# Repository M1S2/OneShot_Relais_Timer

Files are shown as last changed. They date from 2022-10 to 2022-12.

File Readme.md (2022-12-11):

# OneShot Relais Timer

This is a relais timer module that switches a AC mains load ON for a defined period of time.

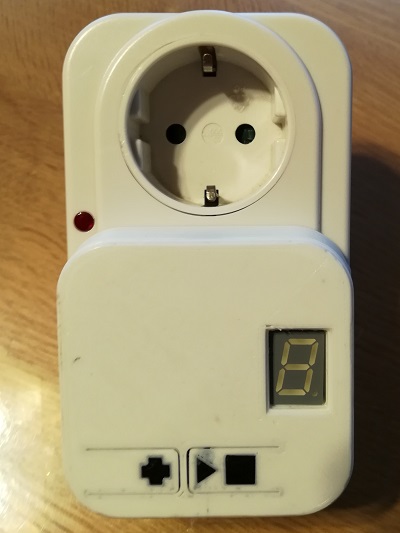
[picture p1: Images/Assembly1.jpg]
Assembly1


## PCB
The schematics and PCBs were created using EAGLE. They were designed to be manufactured using toner transfer method so all traces are as big as possible.

There are two PCBs:
- The Main_PCB contains the microcontroller, the relay and the transformer and regulators used to generate all needed voltages.

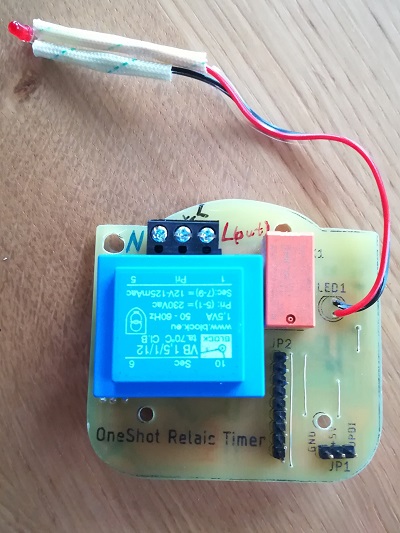
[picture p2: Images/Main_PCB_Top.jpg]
	
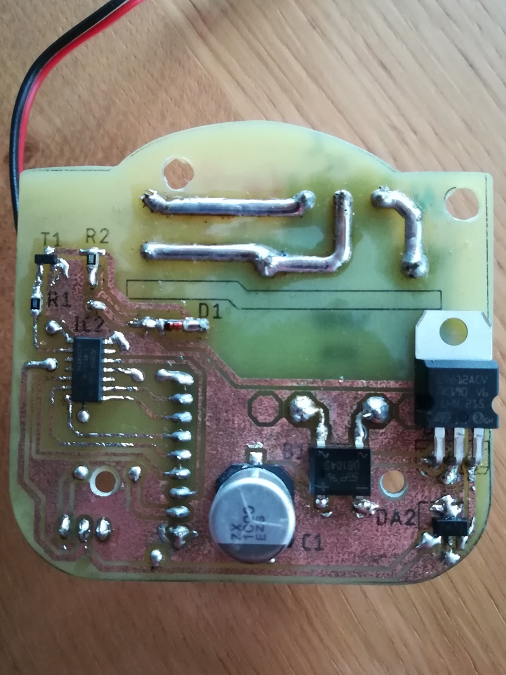
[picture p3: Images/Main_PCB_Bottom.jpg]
	
- The UI_PCB contains the buttons, the 7-segment display and the needed BCD-7-segment driver IC.

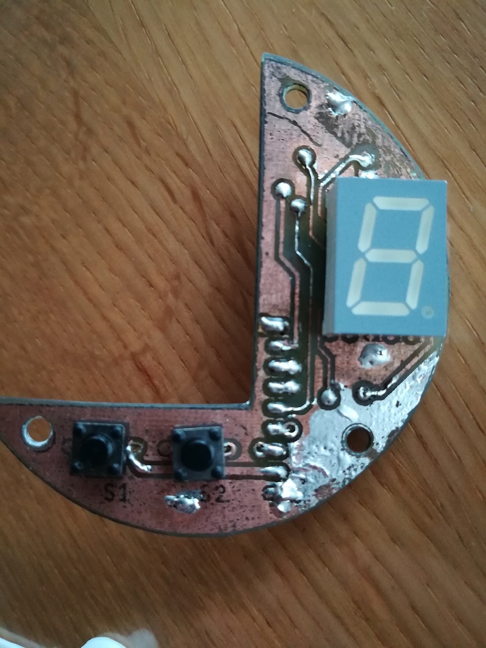
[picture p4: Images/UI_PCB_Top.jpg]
	
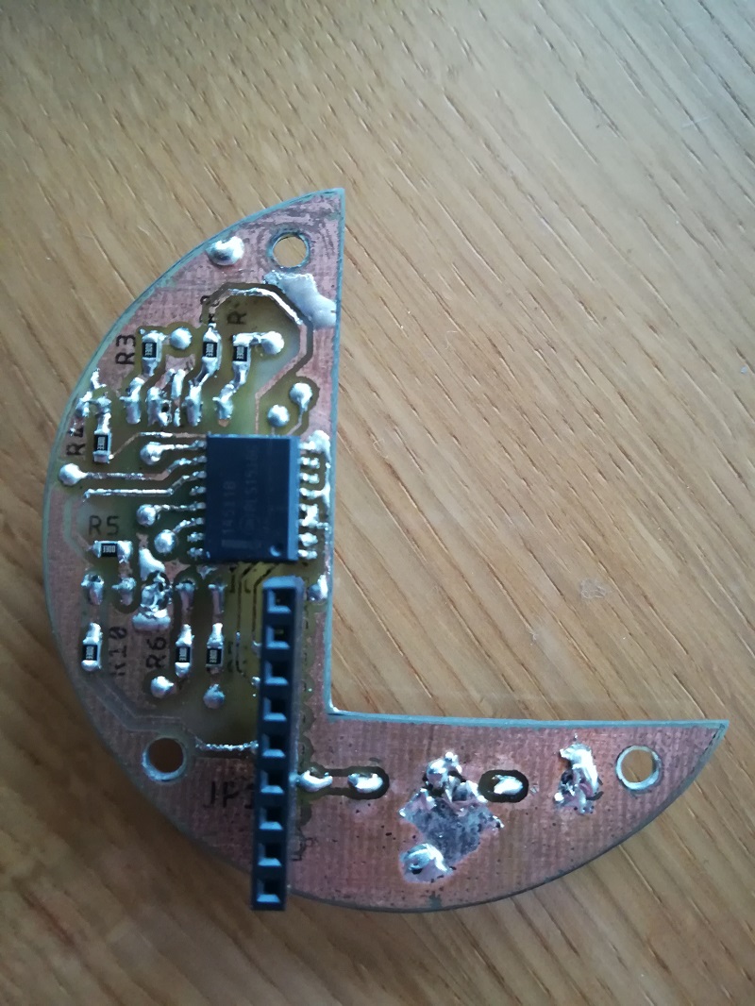
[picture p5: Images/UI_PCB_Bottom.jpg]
	

## Housing
The housing of a mechanical timer was used to containg the PCBs.
The following parts are needed additionally:
- 1x Grundplatte.stl
- 1x Abdeckung_Symbole.stl (should be printed with 2 colors)
- 3x Spacer.stl
- 3x Screw M3x30
- 1x Screw M3x12
- 4x Sheet Metal Screw 15mm long

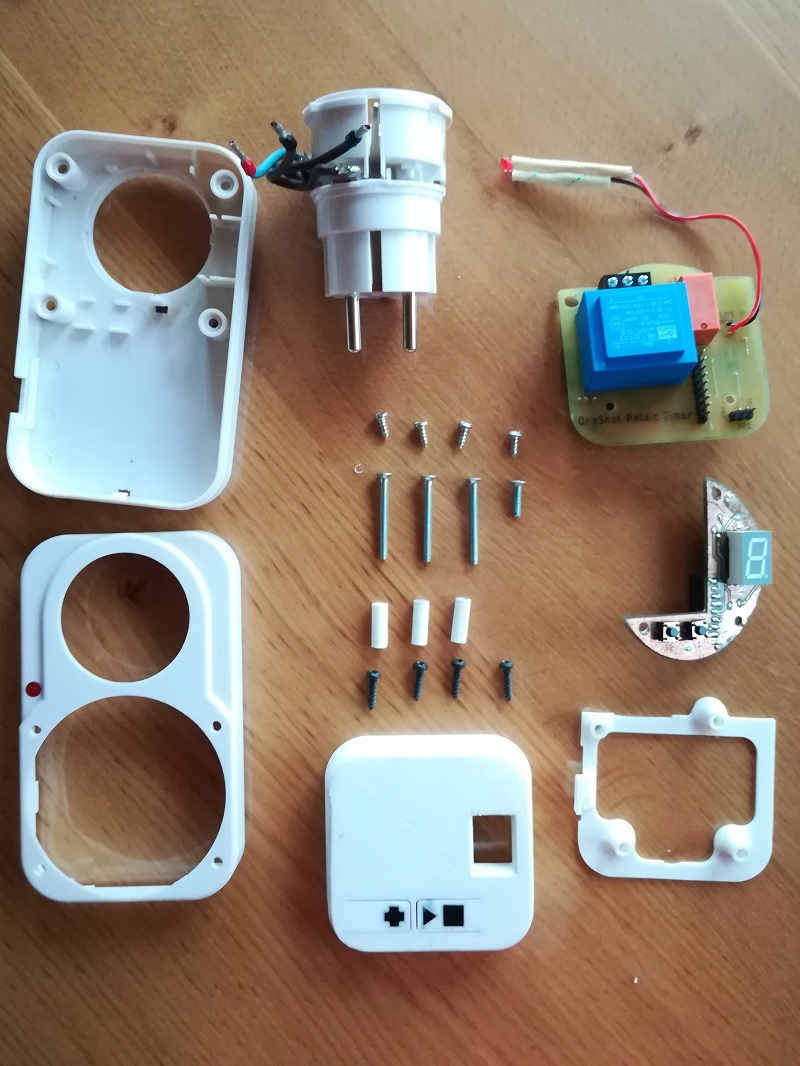
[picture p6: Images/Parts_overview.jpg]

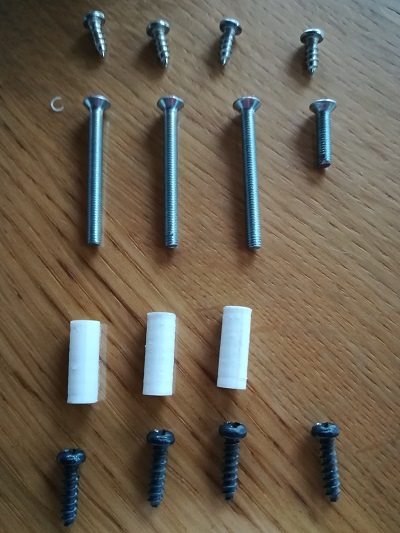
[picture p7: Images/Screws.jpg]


## Software
The software was written for the ATTiny204 microcontroller.

A statemachine is running in the main loop with the following two states:
- SET: The hours can be modified using the set button. The allowed range is 0 to 9. If the start/stop button is pressed, the relay is toggled and the state is changed to COUNTDOWN.
- COUNTDOWN: If the remaining seconds are equal 0 (counted by the PIT interrupt) or the start/stop button is pressed, the relay is toggled and the state is changed to SET.

It uses the following peripherals:
- TCA0: Timer used to query the buttons. It calls the button debounce routine of Peter Dannegger (http://www.mikrocontroller.net/articles/Entprellung).
- PIT: Periodic Interrupt Timer used to count the remaining seconds in COUNTDOWN mode. It also toggles the 7-segment dot in COUNTDOWN mode.

### 0-hours
If the hours are set to 0, the start/stop button can be used to directly toggle the relay. By toggling the relay, an inverted mode is activated, because the relay is toggled when the (normal) countdown is started.
E.g.:
- The set button is used to set the hours to 0
- The start/stop button is used to toggle the relay on.
- The set button is used to set the hours to e.g. 1
- The start/stop button is used to start the countdown > the relay is switched off and on after 1 hour (inverted mode)

### Last set hour
The last set hours are saved when the Countdown is started and are reload on startup.

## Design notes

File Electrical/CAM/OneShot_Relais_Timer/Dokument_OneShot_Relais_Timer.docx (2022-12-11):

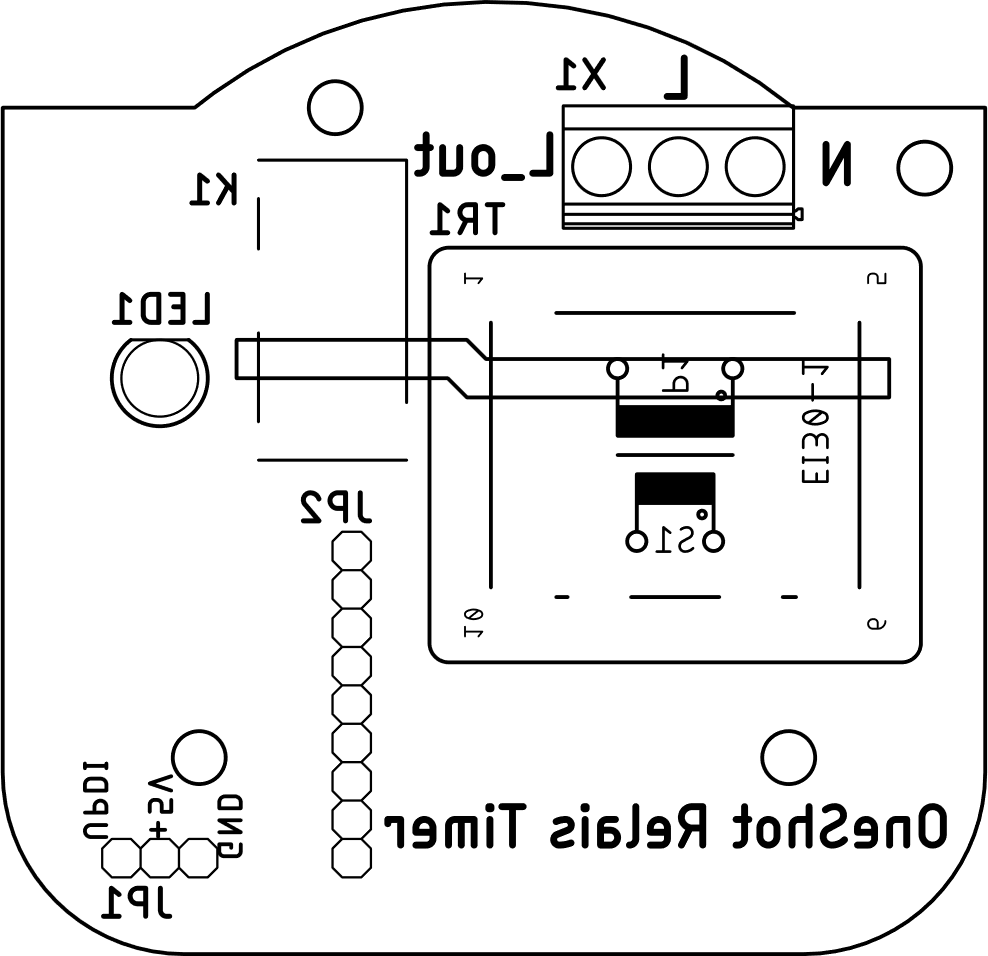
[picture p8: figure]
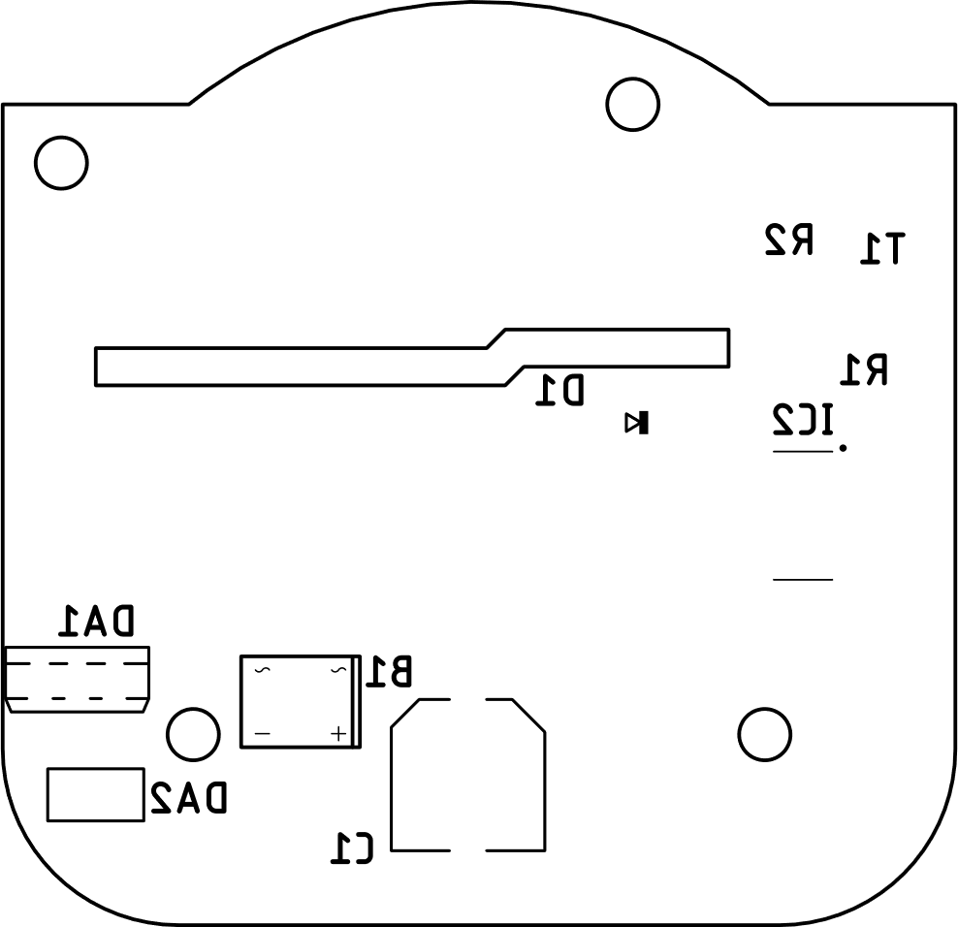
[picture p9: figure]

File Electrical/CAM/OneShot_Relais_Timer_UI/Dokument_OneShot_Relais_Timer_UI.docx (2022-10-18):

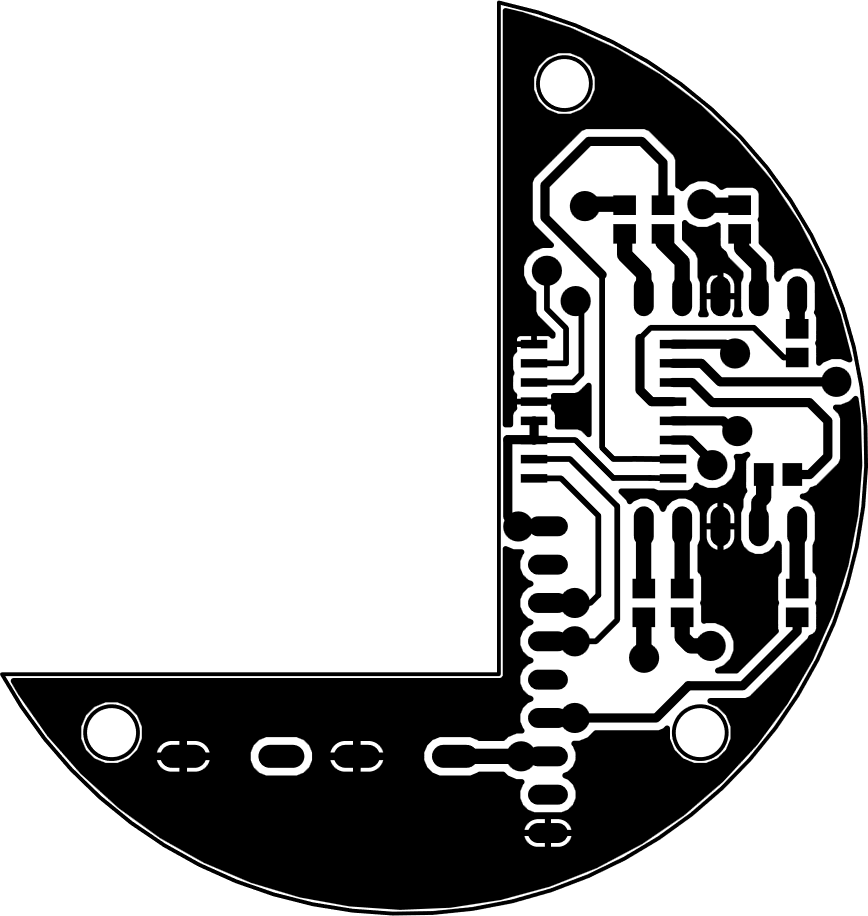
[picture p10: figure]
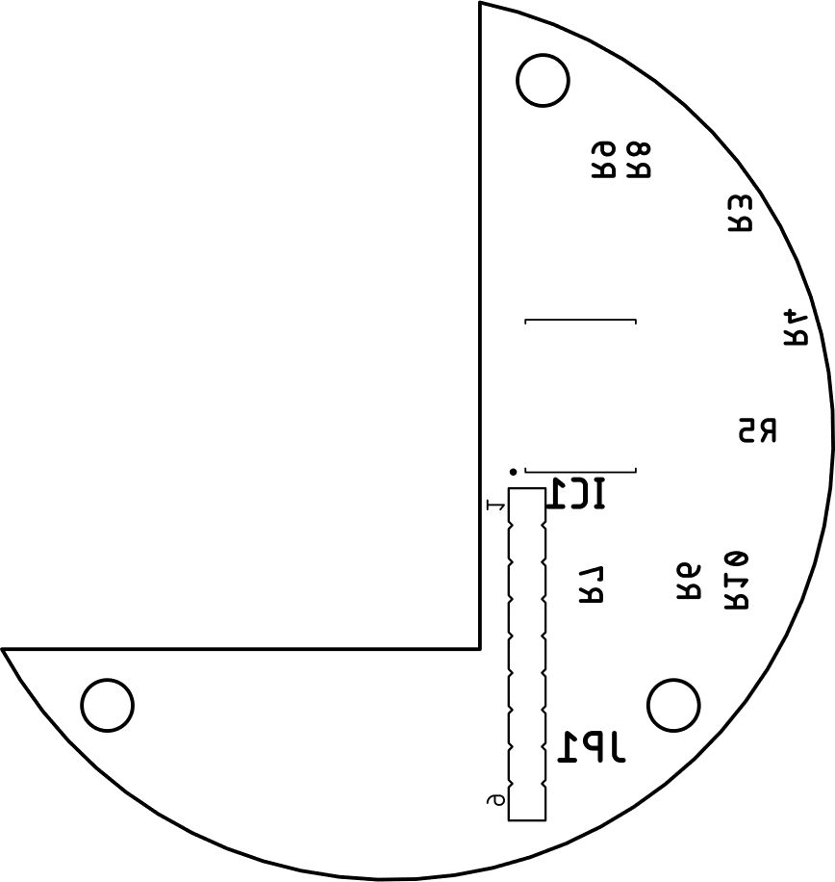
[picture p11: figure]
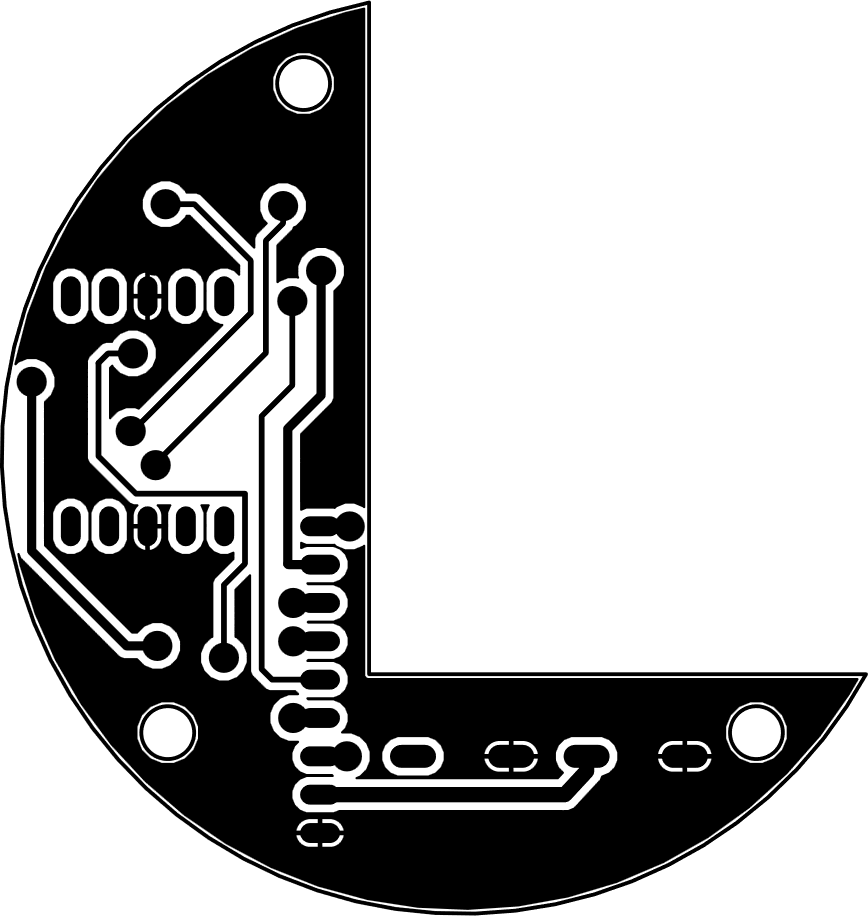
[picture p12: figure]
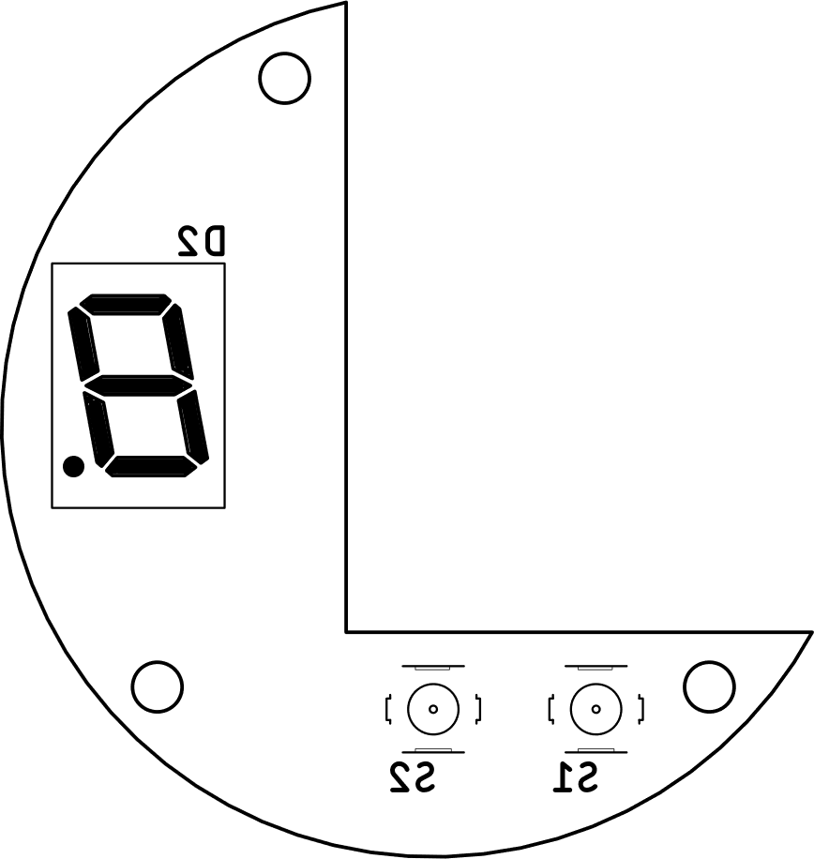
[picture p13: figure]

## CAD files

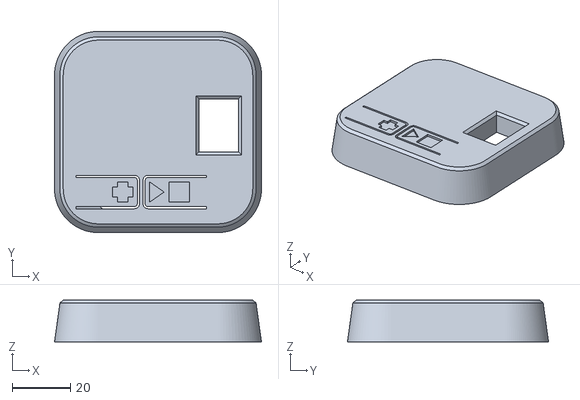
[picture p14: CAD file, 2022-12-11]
Mechanical/Abdeckung.stl
71.0 x 69.0 x 14.4

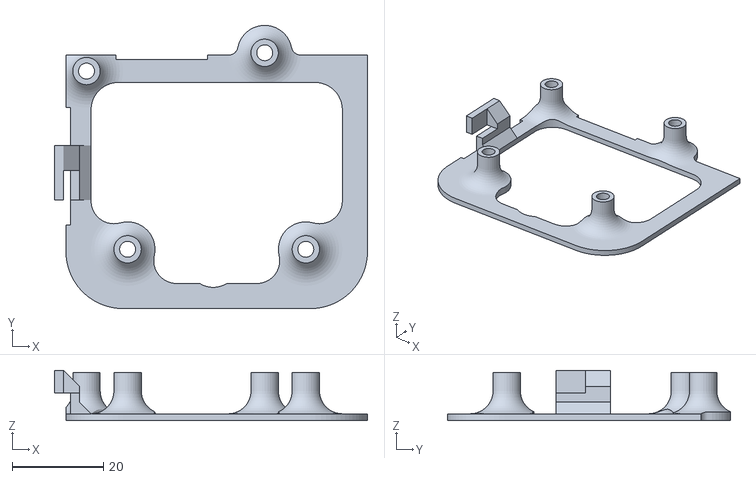
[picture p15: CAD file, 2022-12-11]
Mechanical/Grundplatte.stl
68.5 x 62.0 x 11.0

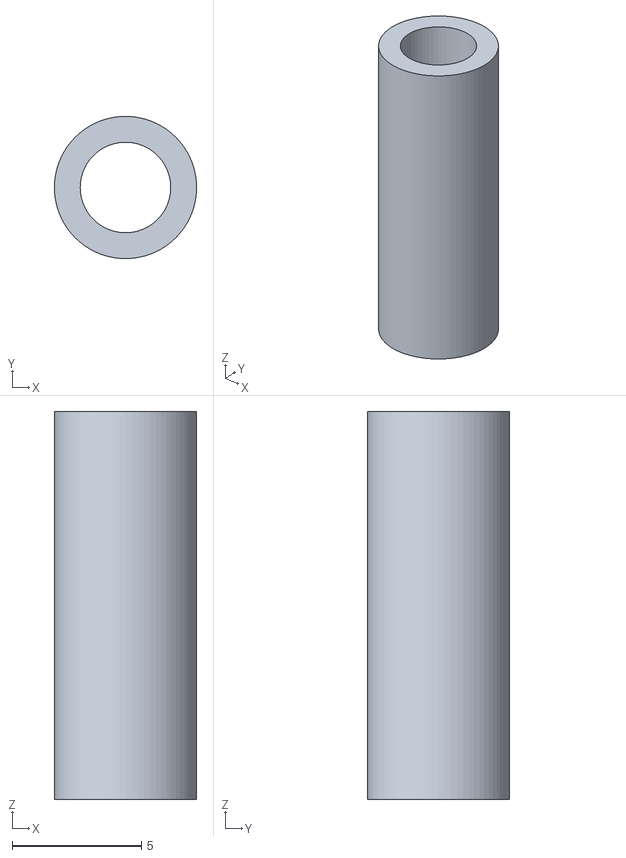
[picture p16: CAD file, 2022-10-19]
Mechanical/Spacer.stl
5.50 x 5.50 x 15.0

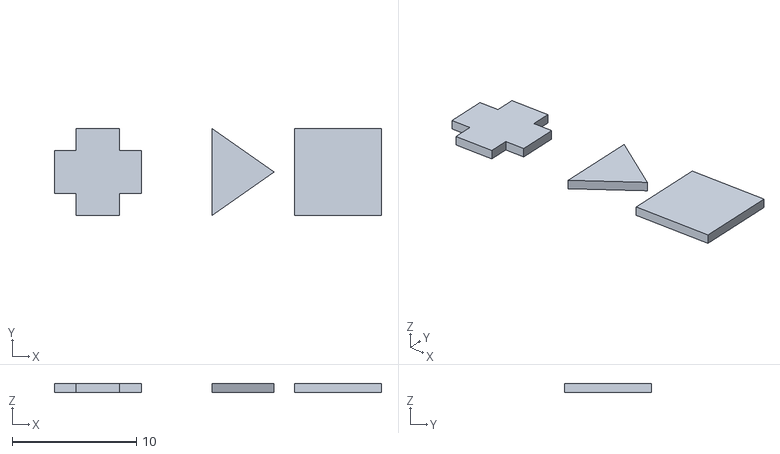
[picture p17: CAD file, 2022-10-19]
Mechanical/Abdeckung_Symbole.stl
26.3 x 7.00 x 0.75

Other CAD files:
Mechanical/Abdeckung.f3d
Mechanical/Abdeckung_Symbole.f3d
Mechanical/Gehaeuse_oben.f3d
Mechanical/Gehaeuse_unten.f3d
Mechanical/Grundplatte.f3d
Mechanical/Spacer.f3d

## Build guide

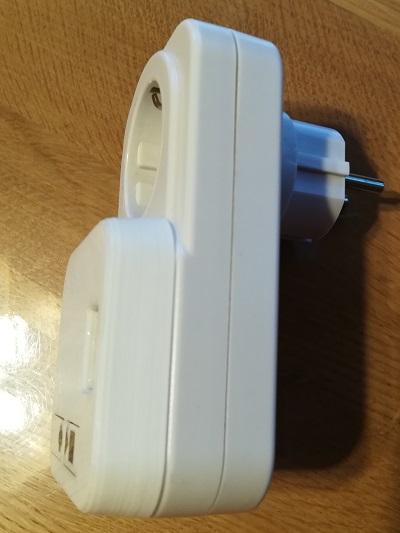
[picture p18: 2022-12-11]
Images/Assembly2.jpg

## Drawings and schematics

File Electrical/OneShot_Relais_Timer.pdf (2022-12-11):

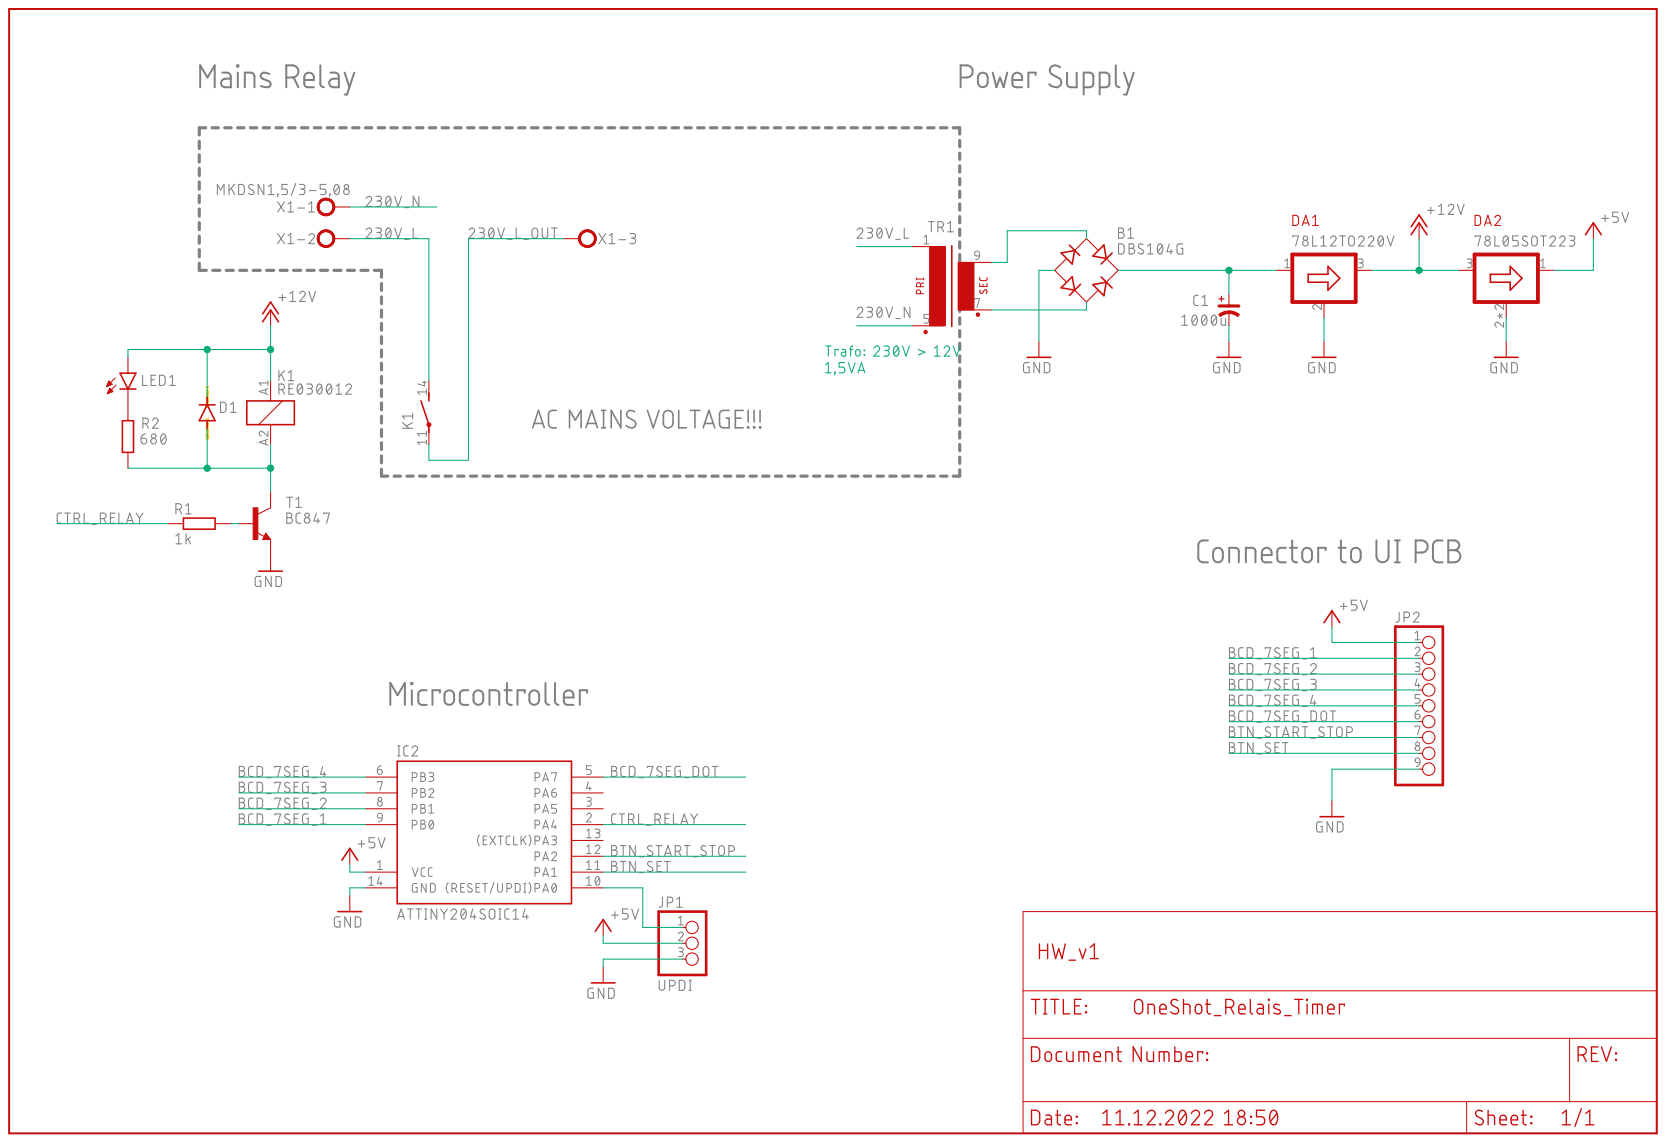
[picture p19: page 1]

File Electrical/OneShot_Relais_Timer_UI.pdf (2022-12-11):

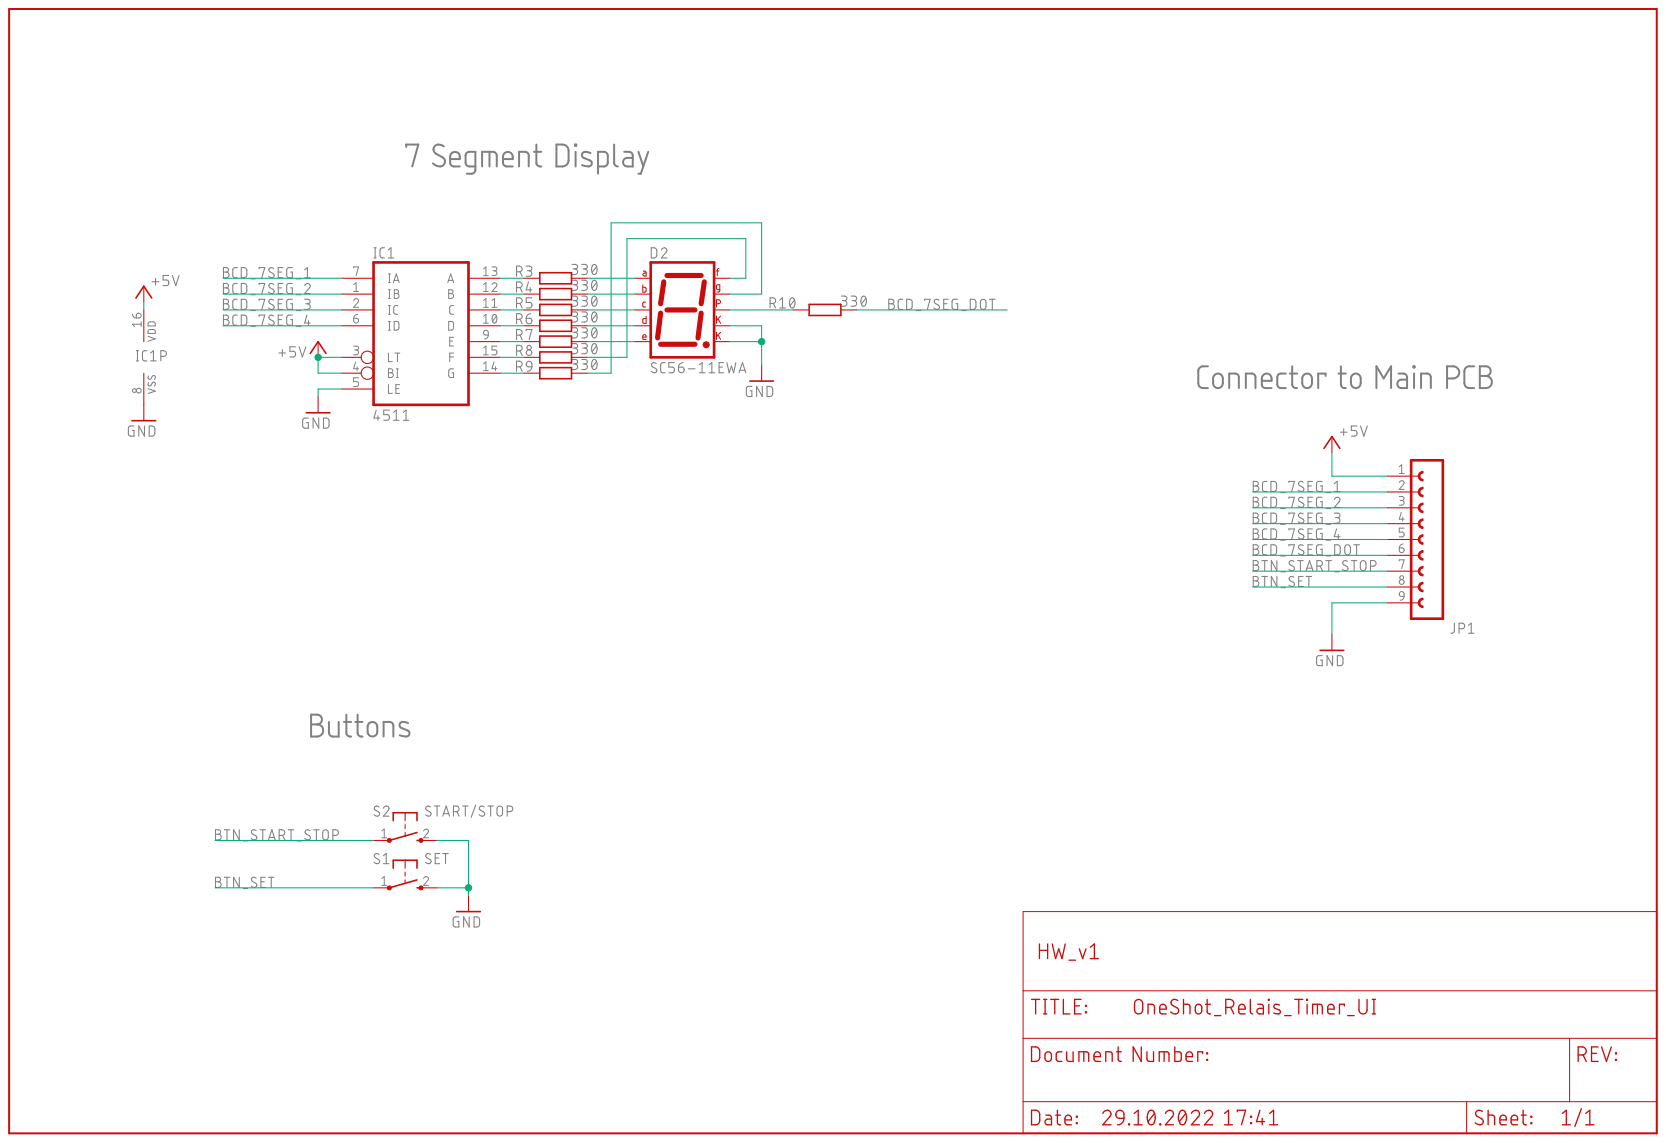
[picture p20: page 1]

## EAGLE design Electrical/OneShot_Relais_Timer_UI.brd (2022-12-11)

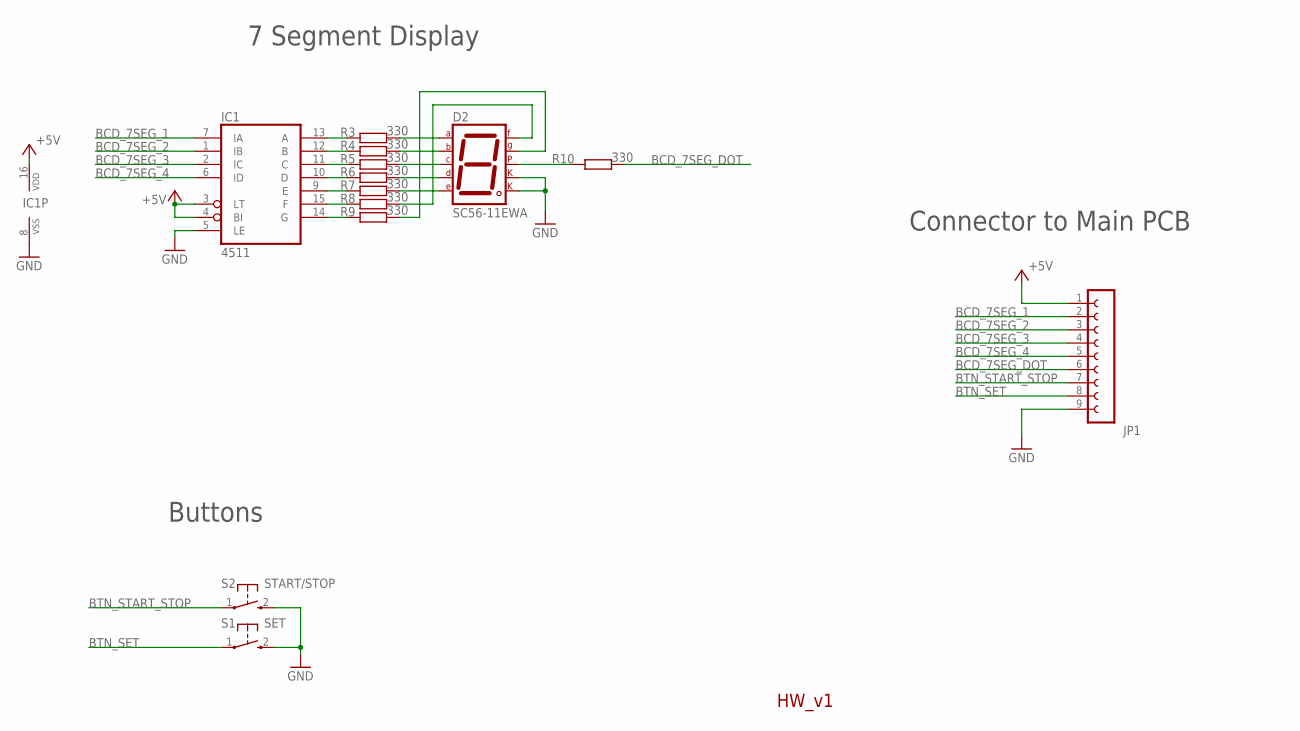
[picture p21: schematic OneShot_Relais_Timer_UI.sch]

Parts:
D2: SC56-11EWA; 7SEG-13
IC1: 4511; SOIC127P1032X265-16L
JP1: FE09-1; FE09
R3, R4, R5, R6, R7, R8, R9, R10: 330; R0805
S1: SET; B3F-10XX
S2: START/STOP; B3F-10XX

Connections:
+5V: IC1.3 (LT), IC1.4 (BI), IC1.16 (VDD), JP1.1
BCD_7SEG_1: IC1.7 (IA), JP1.2
BCD_7SEG_2: IC1.1 (IB), JP1.3
BCD_7SEG_3: IC1.2 (IC), JP1.4
BCD_7SEG_4: IC1.6 (ID), JP1.5
BCD_7SEG_DOT: JP1.6, R10.2
BTN_SET: JP1.8, S1.1
BTN_START_STOP: JP1.7, S2.1
GND: D2.3 (CK1), D2.8 (CK2), IC1.5 (LE), IC1.8 (VSS), JP1.9, S1.2 (S), S2.2 (S)
unnamed: D2.6 (B), R4.2
unnamed: IC1.13 (A), R3.1
unnamed: IC1.12 (B), R4.1
unnamed: IC1.11 (C), R5.1
unnamed: IC1.10 (D), R6.1
unnamed: IC1.9 (E), R7.1
unnamed: IC1.15 (F), R8.1
unnamed: IC1.14 (G), R9.1
unnamed: D2.7 (A), R3.2
unnamed: D2.4 (C), R5.2
unnamed: D2.2 (D), R6.2
unnamed: D2.1 (E), R7.2
unnamed: D2.9 (F), R8.2
unnamed: D2.10 (G), R9.2
unnamed: D2.5 (DP), R10.1

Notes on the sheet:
Buttons
7 Segment Display
Connector to Main PCB
HW_v1

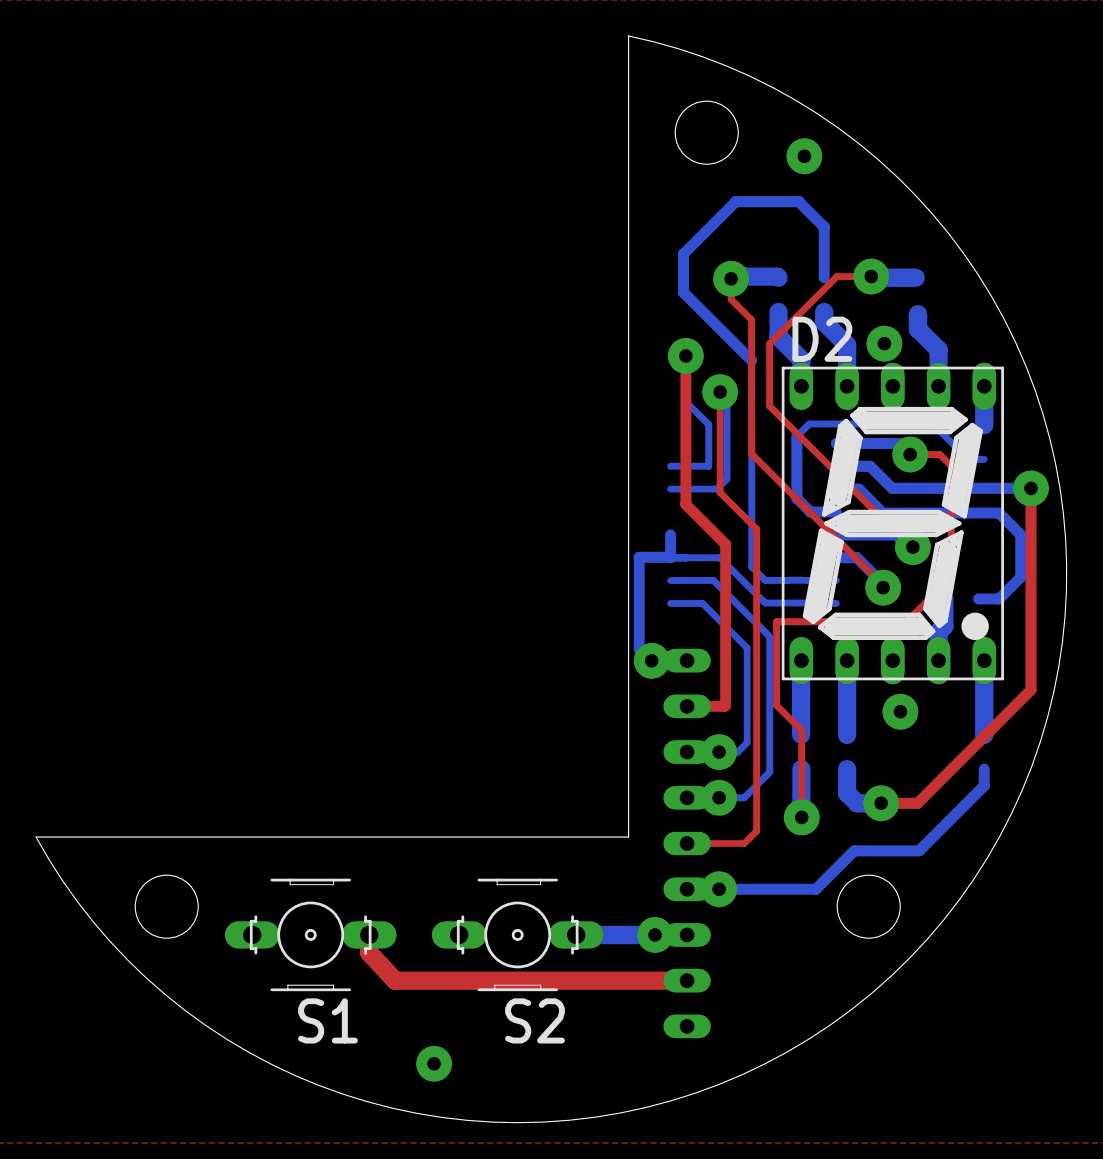
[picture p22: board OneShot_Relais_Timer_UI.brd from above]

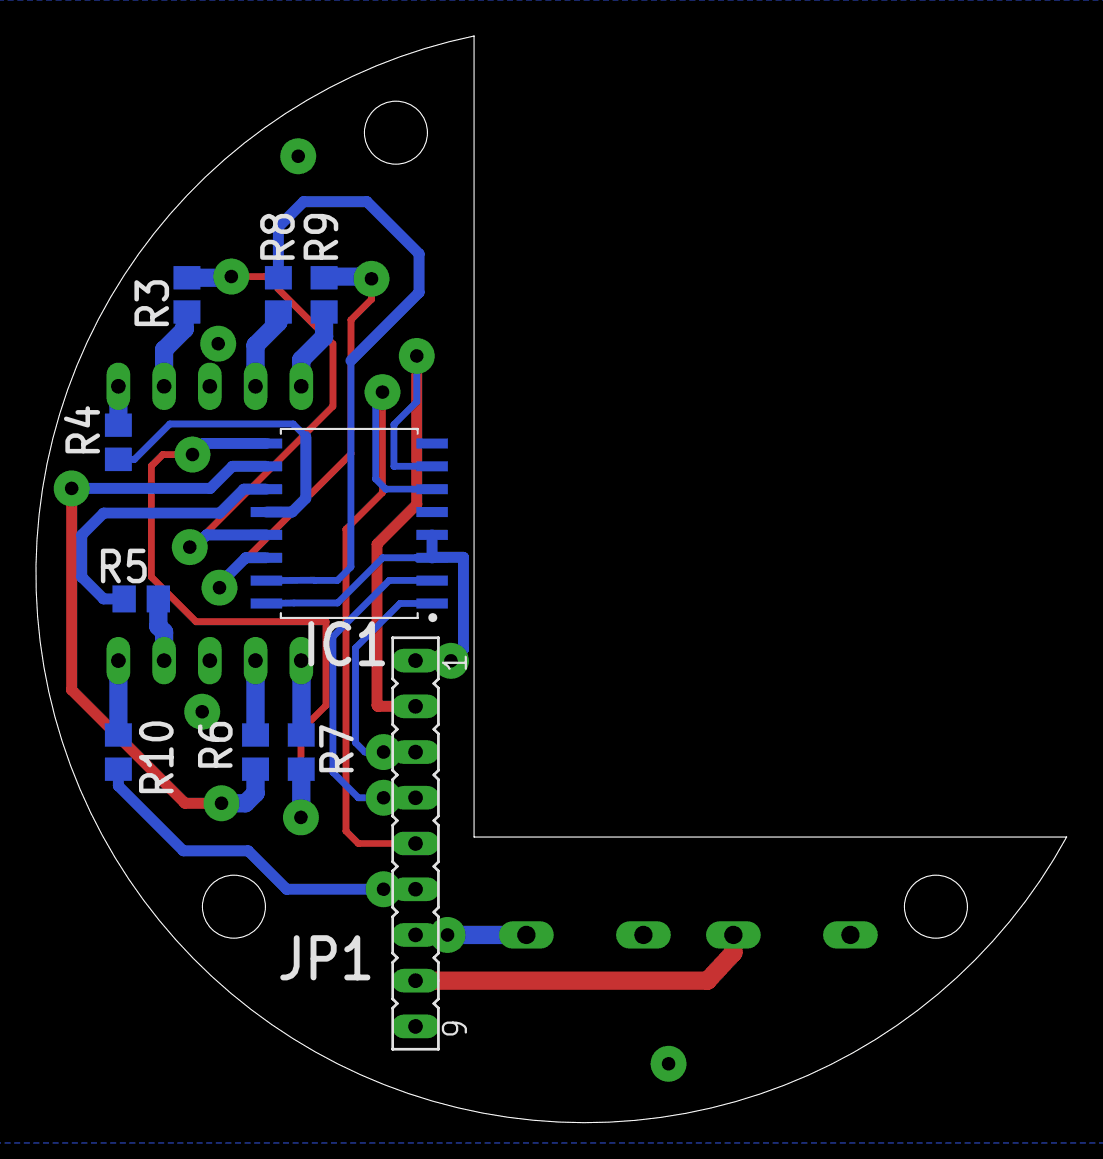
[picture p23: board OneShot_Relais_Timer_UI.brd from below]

Board: 2 copper layers, 57.3 x 60.4 mm, 13 parts (10 on the bottom side), 24 nets.

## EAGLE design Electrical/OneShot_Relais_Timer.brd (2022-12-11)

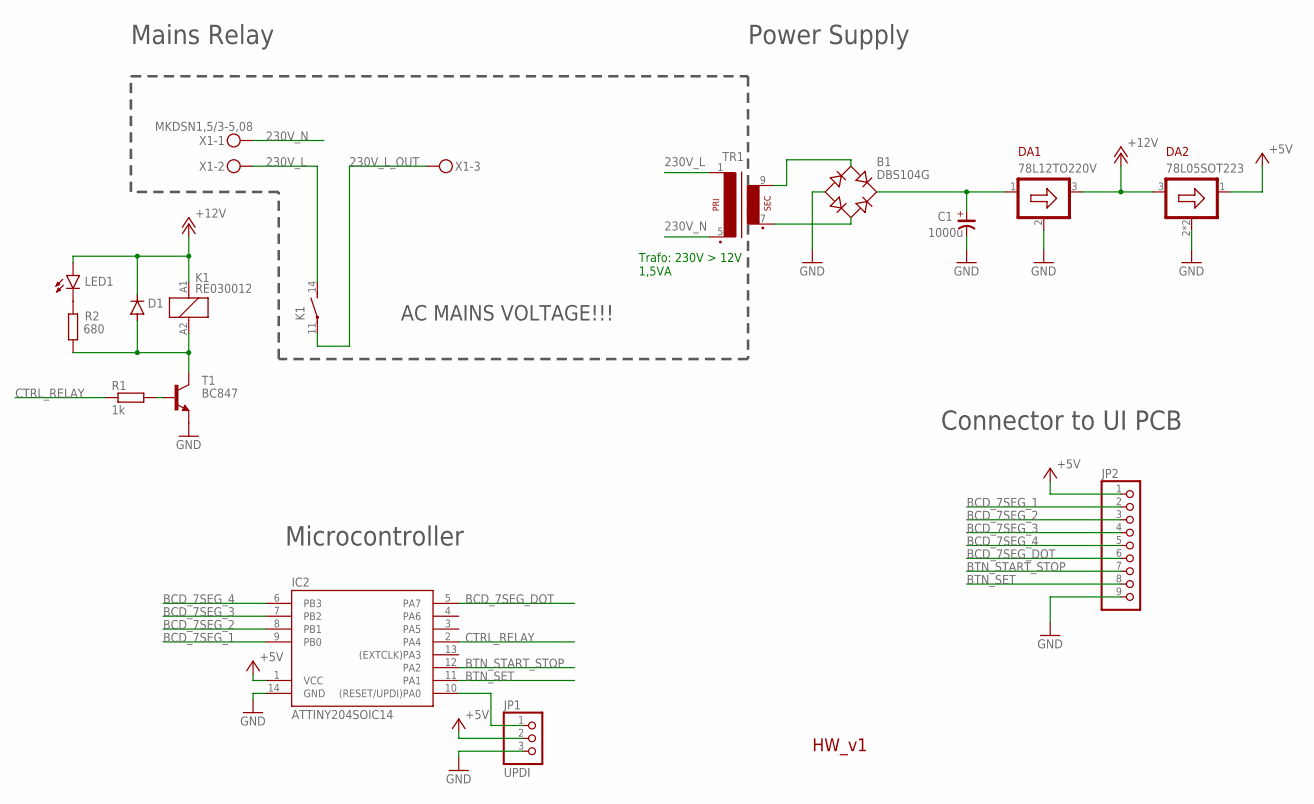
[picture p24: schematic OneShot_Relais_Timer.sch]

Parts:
B1: DBS104G; DBS
C1: 1000u; CSV-G
D1: DIODE-SOD80C; SOD80C
DA1: 78L12TO220V; TO220V
DA2: 78L05SOT223; SOT223
IC2: ATTINY204SOIC14; SOIC127P600X175-14N
JP1: UPDI; 1X03
JP2: PINHD-1X9; 1X09
K1: RE030012; RE-SCHRACK
LED1: LED5MM
R1: 1k; R0805
R2: 680; R0805
T1: BC847; SOT23
TR1: EI30-12.5; EI30-1
X1: MKDSN1,5/3-5,08

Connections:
230V_L: K1.14 (S), TR1.1, X1.2
230V_L_OUT: K1.11, X1.3
230V_N: TR1.5 (P2), X1.1
+5V: DA2.1 (OUT), IC2.1 (VCC), JP1.2, JP2.1
+12V: D1.C, DA1.3 (OUT), DA2.3 (IN), K1.A1 (1), LED1.A
BCD_7SEG_1: IC2.9 (PB0), JP2.2
BCD_7SEG_2: IC2.8 (PB1), JP2.3
BCD_7SEG_3: IC2.7 (PB2), JP2.4
BCD_7SEG_4: IC2.6 (PB3), JP2.5
BCD_7SEG_DOT: IC2.5 (PA7), JP2.6
BTN_SET: IC2.11 (PA1), JP2.8
BTN_START_STOP: IC2.12 (PA2), JP2.7
CTRL_RELAY: IC2.2 (PA4), R1.1
GND: B1.-, C1.-, DA1.2 (GND), DA2.2 (GND), DA2.4 (GND), IC2.14 (GND), JP1.3, JP2.9, T1.2 (E)
unnamed: R1.2, T1.1 (B)
unnamed: LED1.K (C), R2.2
unnamed: D1.A, K1.A2 (2), R2.1, T1.3 (C)
unnamed: B1.+, C1.+, DA1.1 (IN)
unnamed: B1.AC2, TR1.7 (S3)
unnamed: B1.AC1, TR1.9 (S4)
unnamed: IC2.10 ((RESET/UPDI)PA0), JP1.1

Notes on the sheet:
Trafo: 230V > 12V 1,5VA
AC MAINS VOLTAGE!!!
Microcontroller
Connector to UI PCB
Power Supply
Mains Relay
HW_v1

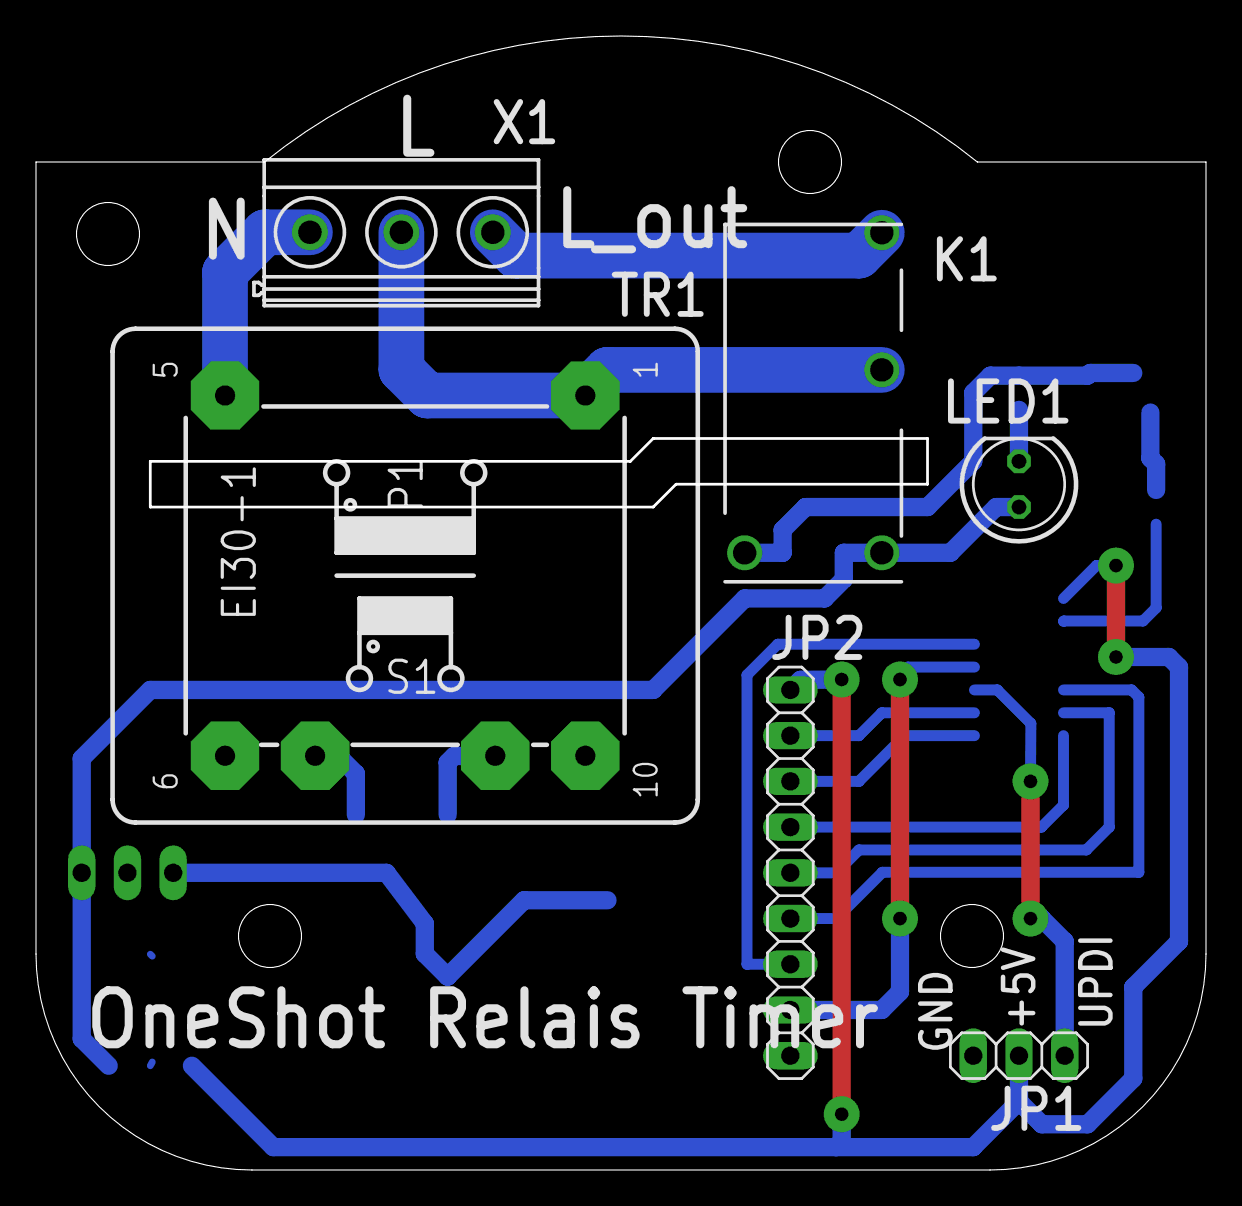
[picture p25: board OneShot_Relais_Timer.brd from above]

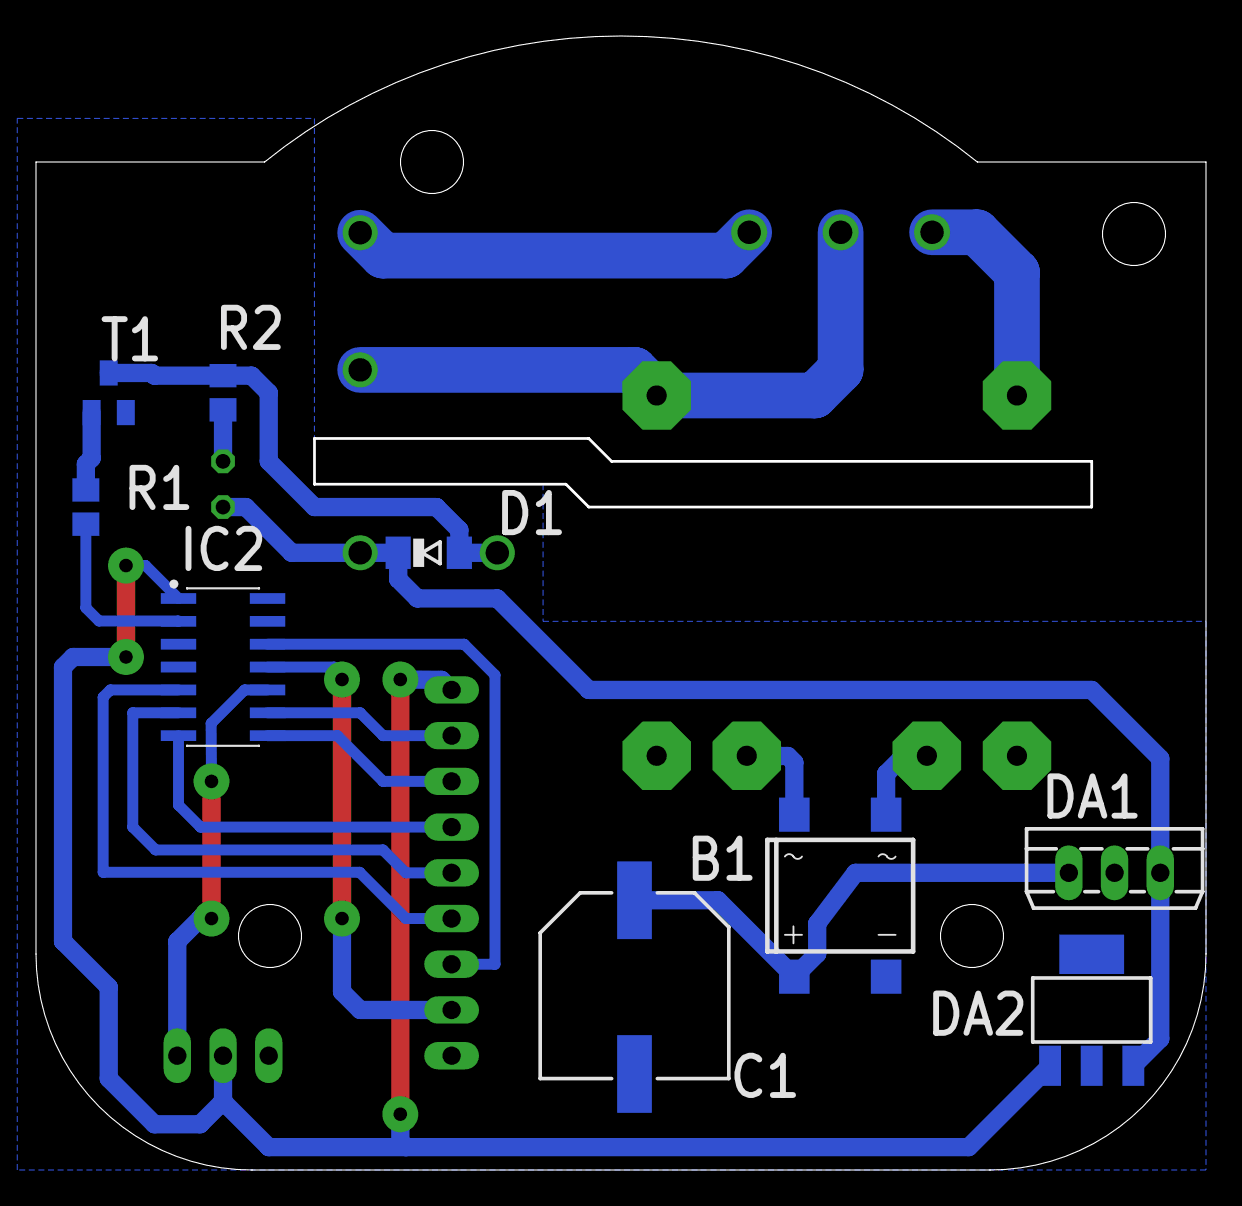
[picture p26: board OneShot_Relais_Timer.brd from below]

Board: 2 copper layers, 65.0 x 63.0 mm, 15 parts (9 on the bottom side), 21 nets.

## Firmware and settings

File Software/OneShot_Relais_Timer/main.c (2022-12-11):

/*
 * OneShot_Relais_Timer.c
 *
 * Created: 09.10.2022 17:48:37
 * Author : Markus
 */ 

#define F_CPU 3333333UL		// 20 MHz / 6
#include <avr/io.h>
#include <util/delay.h>
#include <avr/interrupt.h>
#include <avr/eeprom.h>
#include "Buttons_Debounce.h"

// ################################################################################

#define PIN_CTRL_RELAY		PIN4_bp									/**< Pin used to control the relay and the led showing the relay state */
#define PIN_BCD_7SEG_DOT	PIN7_bp									/**< Pin used to control the 7-segment dot */

#define CTRL_RELAY_ON		PORTA_OUT |= (1<<PIN_CTRL_RELAY);		/**< Switch the relay on */
#define CTRL_RELAY_OFF		PORTA_OUT &= ~(1<<PIN_CTRL_RELAY);		/**< Switch the relay off */
#define CTRL_RELAY_TOGGLE	PORTA_OUT ^= (1<<PIN_CTRL_RELAY);		/**< Toggle the relay state */

#define SET_7SEG(number)	PORTB_OUT = number;						/**< Set the number displayed by the 7-segment-display */
#define DOT_7SEG_ON			PORTA_OUT |= (1<<PIN_BCD_7SEG_DOT);		/**< Switch the 7-segment dot on */
#define DOT_7SEG_OFF		PORTA_OUT &= ~(1<<PIN_BCD_7SEG_DOT);	/**< Switch the 7-segment dot off */
#define DOT_7SEG_TOGGLE		PORTA_OUT ^= (1<<PIN_BCD_7SEG_DOT);		/**< Toggle the 7-segment dot */
		
#define SECONDS_FOR_7SEG_DIGIT	(3600 * TIME_CALIBRATION_FACTOR)	/**< This number of seconds must elapse for the 7 segment digit to change */
#define TIME_CALIBRATION_FACTOR	1.02		// 0.981				/**< Factor that can be used for calibration. 1 = No calib, >1 = countdown was running to fast (slow it down), <1 = countdown was running to slow (speed it up) */

// ################################################################################

/**
 * Enumeration with the statemachine states.
 */
typedef enum States
{
	STATE_SET,							/**< SET state. This is used to modify the hours for the countdown */
	STATE_COUNTDOWN						/**< COUNTDOWN state. This is used to keep the relay on for some time */
}States_t;

volatile States_t currentState;			/**< Variable holding the current statemachine state */
uint8_t setHours;						/**< Variable holding the set hours */
volatile uint16_t remainingSeconds;		/**< Variable used to track the remaining seconds */


EEMEM uint8_t ee_defaultHours;			/**< default number of hours that are read from / saved to EEPROM */

// ################################################################################

/************************************************************************/
/* ISR for the TCA0 Overflow											*/
/* This timer is used for button handling								*/
/************************************************************************/
ISR(TCA0_OVF_vect)
{		
	debounce_timer_interrupt();	
	TCA0.SINGLE.INTFLAGS = TCA_SINGLE_OVF_bm;		//The interrupt flag has to be cleared manually (by writing a '1' to it)
}

/************************************************************************/
/* ISR for the RTC PIT Interrupt										*/
/* This interrupt is used for counting seconds							*/
/************************************************************************/
ISR(RTC_PIT_vect)
{
	if(currentState == STATE_COUNTDOWN)
	{
		DOT_7SEG_TOGGLE
		remainingSeconds--;
	}
	
	RTC.PITINTFLAGS = RTC_PI_bm;					//The interrupt flag has to be cleared manually (by writing a '1' to it)
}

// ################################################################################

int main(void)
{
	// Init IO registers
	PORTA_DIR &= ~PIN1_bm;					// Set BTN_SET Pin (PA1) as input
	PORTA_DIR &= ~PIN2_bm;					// Set BTN_START_STOP Pin (PA2) as input
	PORTA_DIR |= PIN4_bm;					// Set CTRL_RELAY Pin (PA4) as output
	PORTA_DIR |= PIN7_bm;					// Set BCD_7SEG_DOT Pin (PA7) as output
	PORTB_DIR = 0xF;						// Set BCD_7SEG_1 to BCD_7SEG_4 Pins (PB0..PB4) as outputs
	PORTA_PIN1CTRL |= PORT_PULLUPEN_bm;		// Enable Pull-Up for BTN_SET Pin (PA1)
	PORTA_PIN2CTRL |= PORT_PULLUPEN_bm;		// Enable Pull-Up for BTN_START_STOP Pin (PA2)

	// Init Timer (TCA0, used for button handling)
	TCA0.SINGLE.CTRLA = TCA_SINGLE_CLKSEL2_bm | TCA_SINGLE_CLKSEL1_bm | TCA_SINGLE_CLKSEL0_bm | TCA_SINGLE_ENABLE_bm;	// Set Prescaler to 1024 (CLKSEL=7 (Bits 3..1)), Enable Timer (Bit 0)
	TCA0.SINGLE.PER = (uint16_t)(F_CPU / 1024 * 10e-3 + 0.5);															// preload for 10 ms
	TCA0.SINGLE.INTCTRL = TCA_SINGLE_OVF_bm;																			// Enable overflow interrupt
	
	// Init PIT (Periodic interrupt timer, used for counting seconds)
	RTC.CLKSEL = RTC_CLKSEL_INT1K_gc;						// Use internal 1.024 kHz clock
	RTC.PITINTCTRL = RTC_PI_bm;								// Enable PIT interrupt
	RTC.PITCTRLA = RTC_PERIOD_CYC1024_gc | RTC_PITEN_bm;	// Set period to 1024 clock cycles (every second) and enable the PIT

	sei();
	
	currentState = STATE_SET;
	setHours = eeprom_read_byte(&ee_defaultHours);			// read the default hours from the EEPROM
	if(setHours < 1 || setHours > 9)						// read value is out of valid range. Set it to some default value.
	{
		setHours = 3;
	}
	remainingSeconds = 0;
	SET_7SEG(setHours)
	
	DOT_7SEG_OFF
	CTRL_RELAY_OFF
	
	while (1)
	{		
		switch(currentState)
		{
			case STATE_SET:
			{
				if(get_key_press(1 << KEY_SET) || get_key_rpt(1 << KEY_SET))
				{
					setHours++;
					setHours = setHours % 10;
					SET_7SEG(setHours)
				}
				else if(get_key_press(1 << KEY_START_STOP))
				{
					// If hours are set to 0, the relay can be toggled using the start stop button. The countdown can be changed from active during countdown to non-active during countdown.
					if(setHours == 0)
					{
						CTRL_RELAY_TOGGLE
					}
					else
					{
						eeprom_update_byte(&ee_defaultHours, setHours);		// write the setHours to the EEPROM as new default value
						currentState = STATE_COUNTDOWN;
						CTRL_RELAY_TOGGLE
					}
					
					remainingSeconds = setHours * SECONDS_FOR_7SEG_DIGIT;
				}
				else
				{
					// Nothing to do here
				}
				break;
			}
			case STATE_COUNTDOWN:
			{
				if(get_key_press(1 << KEY_START_STOP) || remainingSeconds <= 0)
				{
					currentState = STATE_SET;
					CTRL_RELAY_TOGGLE
					setHours = eeprom_read_byte(&ee_defaultHours);		// read the default hours from the EEPROM
					SET_7SEG(setHours)
					DOT_7SEG_OFF
				}
				else
				{
					SET_7SEG(remainingSeconds / SECONDS_FOR_7SEG_DIGIT)
				}
				
				get_key_press(1 << KEY_SET);		// This is only consumed here to not trigger the set button in SET mode after leaving COUNTDOWN mode (when button was pressed in COUNTDOWN mode)
				
				break;
			}
		}		
	}
}

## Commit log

2022-10-02 Initial version with first schematic draft
    [OneShot_Relais_Timer.brd, OneShot_Relais_Timer.sch]
2022-10-04 First rough placement of components
    [OneShot_Relais_Timer.brd]
2022-10-05 Replaced connectors for AC mains, replaced 12V regulator, added 3D models (trafo, relay, connector X1)
    [OneShot_Relais_Timer.brd, OneShot_Relais_Timer.sch]
2022-10-06 Replaced 12V and 5V regulators, changed trafo type
    [OneShot_Relais_Timer.brd, OneShot_Relais_Timer.sch]
2022-10-06 Moved UI components (7 segment, buttons) to separate PCB
    [OneShot_Relais_Timer.brd, OneShot_Relais_Timer.sch, OneShot_Relais_Timer_UI.brd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]
2022-10-07 Added mounting holes to PCB, moved relay, small adaptions to UI PCB
    [OneShot_Relais_Timer.brd, OneShot_Relais_Timer.sch, OneShot_Relais_Timer_UI.brd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]
2022-10-10 Added mounting hole to PCB
    [OneShot_Relais_Timer.brd]
2022-10-13 Added GND planes, refined routing
    [OneShot_Relais_Timer.brd, OneShot_Relais_Timer_UI.brd]
2022-10-14 Added 3D model for C1 on PCB, improved routing of PCB
    [OneShot_Relais_Timer.brd, OneShot_Relais_Timer.sch]
2022-10-16 Moved 12V regulator to other side, improved texts, improved UI PCB (increased vias and traces)
    [OneShot_Relais_Timer.brd, OneShot_Relais_Timer_UI.brd]
2022-10-18 Replaced BCD 7Segment IC with correct type (footprint), corrected routing of UI PCB
    [OneShot_Relais_Timer_UI.brd, OneShot_Relais_Timer_UI.sch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]
2022-10-19 Added mechanical models for housing
    [Abdeckung.f3d, Abdeckung.stl, Abdeckung_Symbole.f3d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]
2022-10-22 Small adpation to Grundplatte
    [Grundplatte.f3d, Grundplatte.stl]
2022-12-11 Small adaptions to PCBs, schematics, and mechanical components
    [Abdeckung.f3d, Abdeckung.stl, Grundplatte.f3d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]
2022-12-11 Added button debounce code
2022-12-11 Using second timer to count seconds in COUNTDOWN state
2022-12-11 Added 0-hours as feature to toggle the relay directly (and activate inverse mode)
2022-12-11 Replaced timer TCB by Periodic Interrupt Timer (PIT)
    [main.c]
2022-12-11 Removed some not used defines, corrected one small bug (ignore SET button in COUNTDOWN state)
    [main.c]
2022-12-11 Added calibration factor for time counting
